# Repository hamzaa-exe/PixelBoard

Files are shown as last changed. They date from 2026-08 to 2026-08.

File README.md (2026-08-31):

# PixelBoard

### 16×16 WS2812B RGB LED Matrix powered by WLED

PixelBoard is a custom 16×16 RGB LED matrix project using **256 individually addressable WS2812B LEDs** and a custom-designed PCB.

The custom PCB is designed specifically for PixelBoard and provides the ESP32-based controller, USB-C programming, 5V LED power distribution, level-shifted LED data, and a single 3-pin JST output for connecting the LED matrix.

The project uses **WLED** for wireless LED control, allowing the matrix to display animations, colors, effects, 2D patterns, and audio-reactive effects.

Case 3
Case 2
case 1
SCHEMATICS
PixelBoard PCB 1
Pixelboard PCB

## Features

* 16×16 LED matrix
* 256 individually addressable WS2812B LEDs
* Custom ESP32-based controller PCB
* WLED firmware
* Wi-Fi control
* USB-C programming and power input
* 5V LED power output
* 5V logic-level shifting for LED data
* Single 3-pin JST LED matrix connector
* 2D matrix effects
* Audio-reactive effects
* Serpentine LED layout
* Custom enclosure and diffuser

## Hardware

| Component | Quantity |
| --- | ---: |
| Flexible 16×16 NeoPixel RGB LED Matrix | 1 |
| Custom PixelBoard Controller PCB | 1 |
| ESP32-WROOM-32 | 1 |
| 74AHCT125 Logic Level Shifter | 1 |
| CH340C USB-to-Serial Converter | 1 |
| AP2112K-3.3 Voltage Regulator | 1 |
| LED Diffusion Acrylic | 1 |
| JST PH 3-Pin Cable | 1 |
| M2.5 Screws & Standoffs | 1 set |
| 5V 2A Power Supply | 1 |
| USB-C Cable | 1 |

See [`bom.csv`](bom.csv) for the complete Bill of Materials, part numbers, prices, and product links.

## Custom PCB

PixelBoard uses a **custom-designed 2-layer PCB** instead of the Adafruit Sparkle Motion controller.

The PCB integrates the main electronics required to operate the LED matrix:

* ESP32-WROOM-32 controller
* CH340C USB-to-serial interface
* AP2112K 3.3V regulator
* 74AHCT125 5V logic-level shifter
* USB-C connector
* BOOT and RESET buttons
* 2A resettable fuse
* LED power filtering
* Single 3-pin JST LED output

The PCB is designed to fit within approximately **33 × 45 mm**.

## Wiring

The LED matrix connects directly to the custom PCB through the single 3-pin JST output.

```text
Custom PixelBoard PCB
        |
        | +5V  ------------> LED Matrix 5V
        |
        | GND  ------------> LED Matrix GND
        |
        | DATA ------------> LED Matrix DIN
```

The PCB uses a **74AHCT125** to shift the ESP32's 3.3V data signal to a 5V logic-level signal for the WS2812B matrix.

The LED data path is:

```text
ESP32 GPIO21
      |
      v
74AHCT125
      |
      v
330Ω Series Resistor
      |
      v
JST DATA
      |
      v
LED Matrix DIN
```

## Firmware

PixelBoard uses **WLED** rather than custom firmware.

WLED provides:

* Wireless control
* Color and brightness control
* LED effects
* 2D matrix effects
* Presets and playlists
* Audio-reactive effects

WLED can be installed using the official installer:

https://install.wled.me/

For complete installation instructions and PixelBoard-specific settings, see:

**[Firmware Documentation](Firmware/README.md)**

Detailed LED and 2D matrix configuration is available in:

**[WLED Configuration](Firmware/WLED Configuration.md)**

### Main WLED Settings

| Setting | Value |
| --- | --- |
| Controller  | Custom PixelBoard PCB |
| LED Type | WS281x / WS2812B |
| LED Count | 256 |
| Color Order | GRB |
| Data GPIO | 21 |
| Matrix | 16 × 16 |
| First LED | Bottom Left |
| Orientation | Horizontal |
| Serpentine  | ON |

## 2D Matrix

The matrix uses a serpentine layout with the first LED positioned at the bottom-left.

```text
→ → → → → → → → → → → → → → → →
← ← ← ← ← ← ← ← ← ← ← ← ← ← ← ←
→ → → → → → → → → → → → → → → →
← ← ← ← ← ← ← ← ← ← ← ← ← ← ← ←
```

This configuration allows WLED's 2D effects to display correctly across the entire matrix.

## Power

The LED matrix is powered from a **5V 2A power supply** connected to the custom PCB.

The PCB separates the LED power path from the ESP32's 3.3V supply using an onboard **AP2112K-3.3 regulator** and includes a **2A resettable fuse** on the LED power path.

A large bulk capacitor is also placed near the LED output to help reduce voltage fluctuations caused by rapid changes in LED current.

The 256 LEDs can draw significant current at high brightness. For this reason, WLED's brightness and current limiting should be configured appropriately.

Do not operate the complete matrix at unrestricted full-white brightness from a 5V 2A supply.

## PCB Design

The custom PCB was designed in **KiCad**.

### PCB Specifications

| Specification | Value |
| --- | --- |
| PCB Type | Custom 2-layer PCB |
| Board Size | Approximately 33 × 45 mm |
| Controller | ESP32-WROOM-32 |
| LED Data GPIO | GPIO21 |
| Logic Level | 5V LED data |
| LED Output | 3-pin JST |
| LED Supply | 5V |
| Main LED Power Trace  | 1.5 mm |
| Standard Signal Trace | 0.5 mm |
| Ground | F.Cu + B.Cu copper pours |
| USB | USB-C |

The PCB files, schematic, and manufacturing files are located in the `hardware` directory.

## Repository Structure

```text
PixelBoard/
├── README.md
├── bom.csv
├── hardware/
│   ├── schematic/
│   ├── pcb/
│   └── gerbers/
├── firmware/
│   ├── README.md
│   └── WLED Configuration.md
├── enclosure/
└── images/
```

## Resources

* [WLED Installer](https://install.wled.me/)
* [WLED Documentation](https://kno.wled.ge/)
* [16×16 NeoPixel Matrix](https://www.adafruit.com/product/2547)

## License

This project is open-source. See the `LICENSE` file for details.

---

**PixelBoard — 16×16 pixels, 256 LEDs, powered by a custom PCB and WLED.**

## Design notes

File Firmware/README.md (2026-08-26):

# PixelBoard Firmware

PixelBoard uses **WLED** running on the **Adafruit Sparkle Motion** to control a 16×16 WS2812B LED matrix.

WLED provides wireless control of the PixelBoard, including colors, animations, effects, brightness, presets, and playlists.

## Hardware

* **Controller:** Adafruit Sparkle Motion
* **Firmware:** WLED
* **LED type:** WS2812B
* **LED count:** 256
* **Matrix:** 16 × 16
* **Wi-Fi:** 2.4 GHz

## Install WLED

WLED can be installed directly from a compatible desktop web browser.

### Requirements

* Adafruit Sparkle Motion
* USB data cable
* Computer
* Google Chrome, Microsoft Edge, Opera, or another Web Serial-compatible browser
* 2.4 GHz Wi-Fi network

### Installation

1. Connect the Adafruit Sparkle Motion to your computer using a USB data cable.

2. Open the official WLED installer:

   [https://install.wled.me/](https://install.wled.me/)

3. Click **Install**.

4. Select the serial port for the Sparkle Motion.

5. Wait for WLED to finish installing.

6. Configure the Wi-Fi network when prompted.

> **Important:** WLED uses 2.4 GHz Wi-Fi. A 5 GHz-only network will not work.

## Wi-Fi Setup

After installation, WLED will attempt to connect to your Wi-Fi network.

If the Wi-Fi setup does not appear or the board cannot connect, WLED can create its own access point.

1. Open your device's Wi-Fi settings.

2. Connect to:

   `WLED-AP`

3. Use the default password:

   `wled1234`

4. Open the WLED interface.

5. Go to **Config → WiFi Setup**.

6. Enter your normal 2.4 GHz Wi-Fi credentials.

7. Set the mDNS name to:

   `pixelboard`

After connecting to the same Wi-Fi network, PixelBoard can be accessed through:

`http://pixelboard.local`

## LED Configuration

After connecting to WLED, open:

**Config → LED Preferences**

Configure the LED hardware for PixelBoard.

| Setting | Value |
| --- | --- |
| Controller  | Adafruit Sparkle Motion  |
| LED Type | WS281x / WS2812B |
| LED Count | 256 |
| Matrix | 16 × 16 |
| Color Order | GRB |
| Data GPIO | See PixelBoard schematic |

### LED Data Connection

The Sparkle Motion data output is connected to the **DIN** input of the first WS2812B LED.

The LEDs are connected in a continuous chain:

`Sparkle Motion → LED 1 → LED 2 → ... → LED 256`

The exact GPIO used for the data connection should match the GPIO configured in WLED.

## 16×16 Matrix

PixelBoard contains:

**16 × 16 = 256 WS2812B LEDs**

The physical arrangement of the LEDs and the direction of the data path must match the matrix configuration in WLED.

If animations appear:

* Upside down
* Mirrored
* Reversed
* In the wrong sequence

check the LED mapping and matrix settings in WLED.

## Using PixelBoard

Once WLED is configured, connect your phone or computer to the same Wi-Fi network.

Open:

`http://pixelboard.local`

WLED allows you to:

* Change LED colors
* Adjust brightness
* Select animations
* Change animation speed
* Select color palettes
* Create presets
* Create playlists
* Control PixelBoard wirelessly

## Power

The 256 WS2812B LEDs can draw a significant amount of current, especially at high brightness and when displaying white.

The LED matrix should be powered from the dedicated power supply designed for PixelBoard rather than attempting to power all 256 LEDs directly from the Sparkle Motion or USB connection.

For initial testing, keep the brightness/current limit low.

## Firmware Updates

PixelBoard does not use custom firmware.

**WLED is the firmware used by the Adafruit Sparkle Motion.**

When updating WLED, check the PixelBoard configuration afterward, especially:

* LED count
* Data GPIO
* Color order
* Matrix/LED mapping
* Brightness/current limits

## Resources

* WLED Installer: [https://install.wled.me/](https://install.wled.me/)
* WLED Documentation: [https://kno.wled.ge/](https://kno.wled.ge/)
* Adafruit Sparkle Motion documentation: [https://learn.adafruit.com/adafruit-sparkle-motion](https://learn.adafruit.com/adafruit-sparkle-motion)
* WLED GitHub: [https://github.com/Aircoookie/WLED](https://github.com/Aircoookie/WLED)

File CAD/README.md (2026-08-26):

Folder contains 3D Parts of PixelBoard

**Build Volume**

The parts require a 3D printer with a minimum build volume of:

174mm (X) x 174mm (Y) x 22mm (Z)

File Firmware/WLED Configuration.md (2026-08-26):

# WLED Configuration

PixelBoard uses **WLED** on the **Adafruit Sparkle Motion** to control a 16×16 WS2812B LED matrix.

After installing WLED, configure the LED matrix using the settings below.

## LED Settings

Open the WLED interface and go to:

**Config → LED Preferences**

Under **LED Outputs**, use the following settings:

| Setting | Value |
| --- | --- |
| LED Type | WS281x |
| mA/LED | 55 mA (typ. 5V WS281x) |
| Color Order | GRB |
| Start | 0 |
| Length | 256 |
| Data GPIO | 21 |

Click **Save** after entering the settings.

## 2D Configuration

To configure the 16×16 matrix correctly, go to:

**Config → 2D Configuration**

Under **2D Setup**:

* **2D Mode:** 2D Matrix

Under **LED Panel Layout**:

| Setting | Value |
| --- | --- |
| 1st LED | Bottom Left |
| Orientation | Horizontal  |
| Serpentine  | ON |
| Width | 16 |
| Height | 16 |

The resulting matrix contains:

**16 × 16 = 256 LEDs**

Click **Save** after applying the settings.

### LED Layout

The matrix uses a **serpentine layout**, meaning each row alternates its direction.

```text
→ → → → → → → → → → → → → → → →
← ← ← ← ← ← ← ← ← ← ← ← ← ← ← ←
→ → → → → → → → → → → → → → → →
← ← ← ← ← ← ← ← ← ← ← ← ← ← ← ←
              ...
→ → → → → → → → → → → → → → → →
← ← ← ← ← ← ← ← ← ← ← ← ← ← ← ←
```

The first LED is located at the **bottom-left** of the matrix.

## 2D Effects

WLED provides effects specifically designed for 2D LED matrices.

To find them:

1. Open the WLED homepage.
2. Go to the **Effects** section.
3. Click the effect search box.
4. Select the **Matrix** category.
5. WLED will display the available 2D effects.
6. Select an effect to display it on PixelBoard.

These effects take advantage of the 16×16 matrix rather than treating the LEDs as a simple 1D strip.

## Audio Reactive Configuration

PixelBoard can also use WLED's audio-reactive features with an I2S digital microphone.

Open:

**Config → Usermods**

Find the **Audio Reactive** section and enable it.

### Digital Microphone

Under the **Digitalmic** type dropdown, select:

**Generic I2S**

Use the following pin configuration:

| I2S Signal | GPIO |
| --- | ---: |
| I2S SD | 25 |
| I2S WS | 33 |
| I2S SCK | 26 |

Enable **Audio Reactive** and click **Save**.

## Configuration Summary

| Category | Setting |
| --- | --- |
| Controller | Adafruit Sparkle Motion |
| Firmware | WLED |
| LED Type | WS281x / WS2812B |
| LED Count | 256 |
| Matrix | 16 × 16 |
| Color Order | GRB |
| Data GPIO | 21 |
| First LED | Bottom Left |
| Orientation | Horizontal |
| Serpentine | ON |
| 2D Mode | 2D Matrix |
| Audio Reactive  | Enabled |
| Microphone Type | Generic I2S |
| I2S SD | GPIO 25 |
| I2S WS | GPIO 33 |
| I2S SCK | GPIO 26 |

> **Important:** These GPIO assignments are based on the Adafruit Sparkle Motion configuration described in the project documentation. Make sure your PixelBoard wiring matches these pins before powering the matrix.

## Resources

* [WLED Installer](https://install.wled.me/)
* [WLED Documentation](https://kno.wled.ge/)
* [Adafruit Sparkle Motion](https://learn.adafruit.com/adafruit-sparkle-motion)

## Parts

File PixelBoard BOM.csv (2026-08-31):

Component | Quantity | Unit Price (USD) | Product URL
Flexible 16x16 NeoPixel RGB LED Matrix | 1 | 9 | https://www.aliexpress.com/item/1005003901833984.html?curPageLogUid=ZZG4hwHSGnFo
ESP32-WROOM-32 | 1 | 6 | https://www.aliexpress.com/item/33050337615.html?curPageLogUid=FKexapiNrazp
Black LED Diffusion Acrylic Panel 12 x 12 - 2.6mm | 1 | 6 | https://www.aliexpress.com/item/1005004967054575.html?curPageLogUid=s7XI3nJbx4EO
STEMMA JST PH 2mm 3-Pin to Male Header Cable - 200mm | 1 | 1.25 | https://www.aliexpress.com/item/1005010521591320.html?curPageLogUid=JzLczT8vxpuK
JST PH 2mm 3-Pin Socket to Color Coded Cable - 200mm | 1 | 3 | https://www.aliexpress.com/item/1005010521591320.html?curPageLogUid=JzLczT8vxpuK
Black Nylon Machine Screw and Stand-off Set - M2.5 Thread | 1 | 3 | https://www.aliexpress.com/item/1005012768812211.html?curPageLogUid=2NIQYpsG7G1R
Pink and Purple Woven USB A to USB C Cable - 2 meters | 1 | 2 | https://www.aliexpress.com/ssr/300000512/BundleDeals2?productIds=1005008494569058:12000045396663358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
74AHCT125 | 1 | 5 | https://www.aliexpress.com/item/1005012698716814.html?curPageLogUid=ZHdj8GMJHjQv
CH340C | 1 | 5 | https://www.aliexpress.com/item/1005009751056321.html?curPageLogUid=WTwREXOZFUJY
AP2112K-3.3 | 1 | 3 | https://www.aliexpress.com/item/1005005807114594.html?curPageLogUid=2otpah4skVdC
2A polyfuse 1206 | 1 | 2 | https://www.aliexpress.com/item/1005005750933997.html?curPageLogUid=ZtGeeKRbMEdm
TL3305A Tactile Switch | 2 | 3 | https://www.aliexpress.com/item/1005006049127824.html?curPageLogUid=on0BWJc9AisX
0805 SMD Resisors | 5 | 10 | https://www.aliexpress.com/item/4000095368506.html?curPageLogUid=R3eLSOwJxnAt
0805 SMD Capacitors | 6 | 10 | https://www.aliexpress.com/item/1005008651094452.html?curPageLogUid=0jGhCAofqSR0
Electrolytic Capacitor | 1 | 3 | https://www.aliexpress.com/item/32910379011.html?curPageLogUid=w4WyyqBZ0N1G
PCB + shipping | 5 | 20 | https://jlcpcb.com
3D Printing | 1 | 19 | Printing Legion
Ali Express Shipping |  | 25
Total |  | 130.25

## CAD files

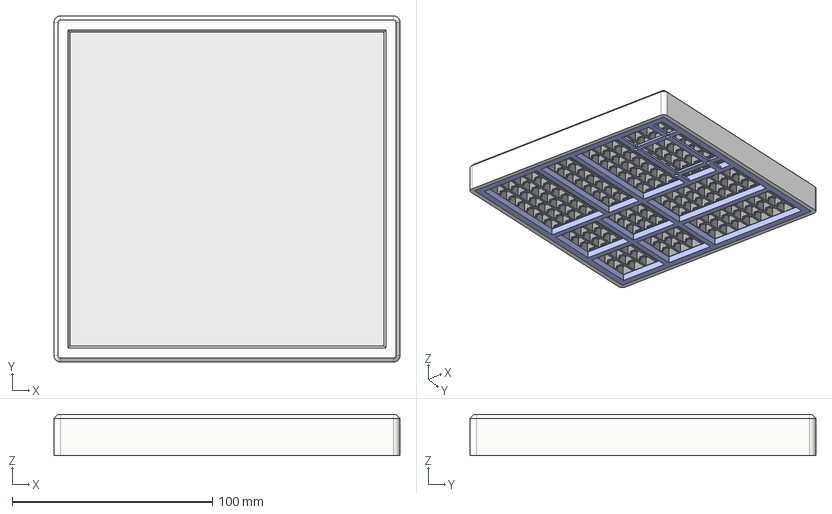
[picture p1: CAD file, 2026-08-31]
CAD/PixelBoard.step
172.8 x 172.8 x 20.6 mm
Grid
Cover
Acrylic
Insert

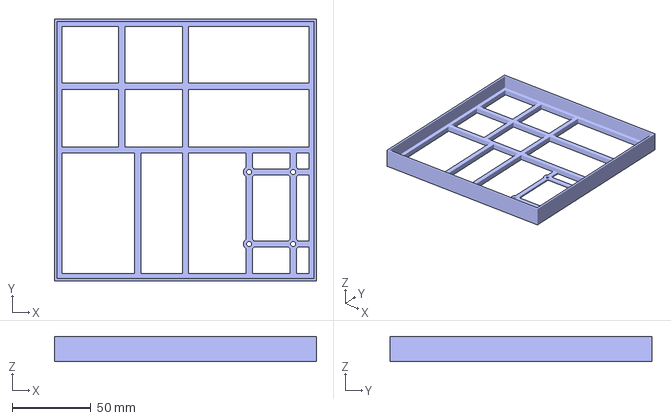
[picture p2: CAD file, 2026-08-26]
Production/16x Display Insert.3mf
166.4 x 166.4 x 16.0 mm

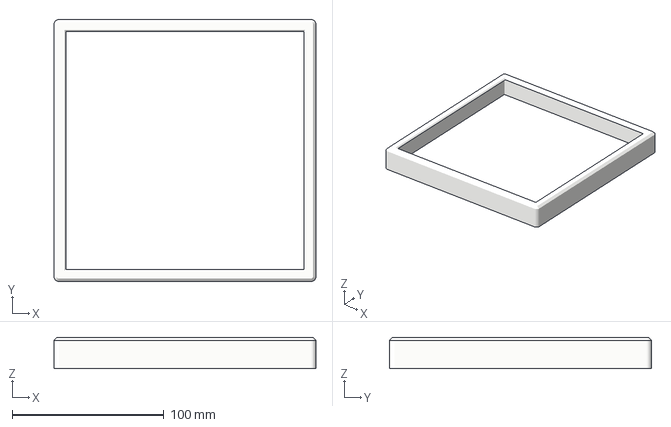
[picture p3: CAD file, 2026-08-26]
Production/16x Display Cover.3mf
172.8 x 172.8 x 20.6 mm

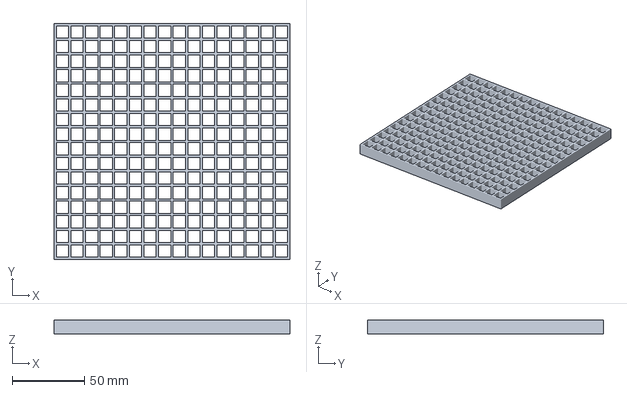
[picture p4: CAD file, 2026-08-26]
Production/16x Display Grid.3mf
163.2 x 163.2 x 10.0 mm

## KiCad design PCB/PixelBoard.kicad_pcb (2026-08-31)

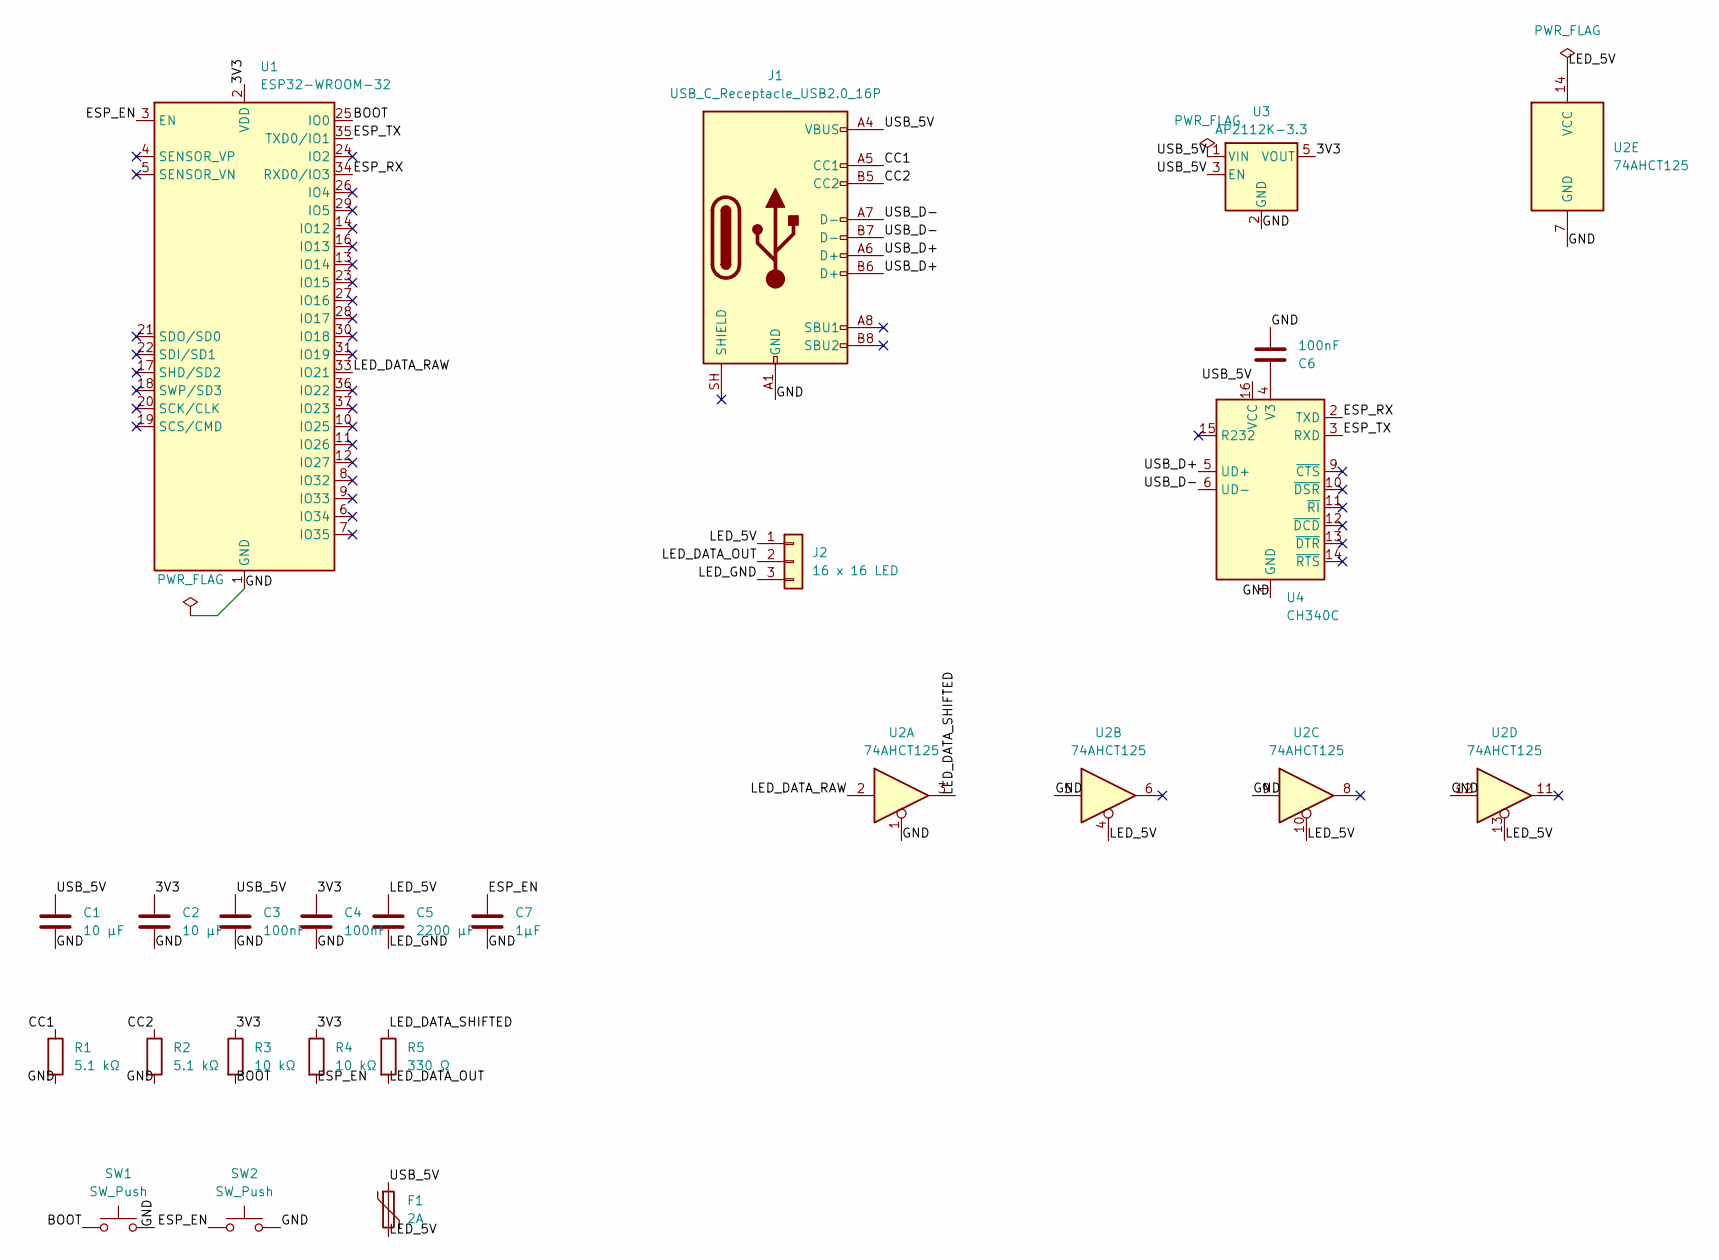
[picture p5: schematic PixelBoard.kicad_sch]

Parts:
C1, C2: 10 µF; C_0805_2012Metric
C3, C4, C6: 100nF; C_0805_2012Metric
C5: 2200 µF; CP_Radial_D8.0mm_P3.50mm
C7: 1µF; C_0805_2012Metric
F1: 2A; Fuse_1206_3216Metric
J1: USB_C_Receptacle_USB2.0_16P; USB_C_Receptacle_HRO_TYPE-C-31-M-12
J2: 16 x 16 LED; JST_PH_B3B-PH-K_1x03_P2.00mm_Vertical
R1, R2: 5.1 kΩ; R_0805_2012Metric
R3, R4: 10 kΩ; R_0805_2012Metric
R5: 330 Ω; R_0805_2012Metric
SW1, SW2: SW_Push; SW_SPST_TL3305A
U1: ESP32-WROOM-32
U2: 74AHCT125; SOIC-14_3.9x8.7mm_P1.27mm
U3: AP2112K-3.3; SOT-23-5
U4: CH340C; SOIC-16_3.9x9.9mm_P1.27mm

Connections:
/3V3: C2.1, C4.1, R3.1, R4.1, U1.2 (VDD), U3.5 (VOUT)
/BOOT: R3.2, SW1.1, U1.25 (IO0)
/CC1: J1.A5 (CC1), R1.1
/CC2: J1.B5 (CC2), R2.1
/ESP_EN: C7.1, R4.2, SW2.1, U1.3 (EN)
/ESP_RX: U1.34 (RXD0/IO3), U4.2 (TXD)
/ESP_TX: U1.35 (TXD0/IO1), U4.3 (RXD)
/GND: C1.2, C2.2, C3.2, C4.2, C6.2, C7.2, J1.A1 (GND), J1.A12 (GND), J1.B1 (GND), J1.B12 (GND), R1.2, R2.2, SW1.2, SW2.2, U1.1 (GND), U1.15 (GND), U1.38 (GND), U1.39 (GND), U2.1, U2.5, U2.7 (GND), U2.9, U2.12, U3.2 (GND), U4.1 (GND)
/LED_5V: C5.1, F1.2, J2.1, U2.4, U2.10, U2.13, U2.14 (VCC)
/LED_DATA_OUT: J2.2, R5.2
/LED_DATA_RAW: U1.33 (IO21), U2.2
/LED_DATA_SHIFTED: R5.1, U2.3
/LED_GND: C5.2, J2.3
/USB_5V: C1.1, C3.1, F1.1, J1.A4 (VBUS), J1.A9 (VBUS), J1.B4 (VBUS), J1.B9 (VBUS), U3.1 (VIN), U3.3 (EN), U4.16 (VCC)
/USB_D+: J1.A6 (D+), J1.B6 (D+), U4.5 (UD+)
/USB_D-: J1.A7 (D-), J1.B7 (D-), U4.6 (UD-)
unnamed: C6.1, U4.4 (V3)

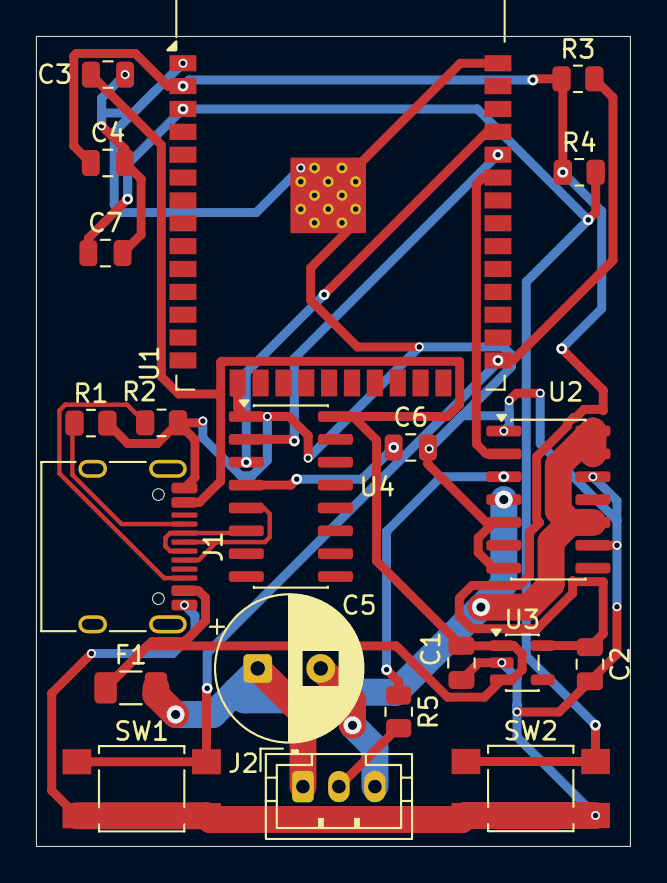
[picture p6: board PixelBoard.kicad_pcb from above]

Board: 2 copper layers, 33.0 x 45.0 mm, 21 parts (0 on the bottom side), 17 nets.

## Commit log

2026-08-26 Rename 16x16 Sparkle Motion Display v7.step to PixelBoard.step
    [16x16 Sparkle Motion Display v7.step, PixelBoard.step]
2026-08-26 Document WLED configuration for PixelBoard
    Added detailed configuration instructions for WLED on the Adafruit Sparkle Motion controlling a 16×16 WS2812B LED matrix, including LED settings, 2D configuration, effects, audio reactive setup, and 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
2026-08-26 Update PixelBoard BOM.csv
    [PixelBoard BOM.csv]
2026-08-26 Revise README.md with detailed project information
    Expanded project description and added detailed sections on features, hardware, wiring, firmware, and repository structure.
2026-08-27 Revise PixelBoard BOM with new prices and links
    Updated prices and product URLs in the BOM.
    [PixelBoard BOM.csv]
